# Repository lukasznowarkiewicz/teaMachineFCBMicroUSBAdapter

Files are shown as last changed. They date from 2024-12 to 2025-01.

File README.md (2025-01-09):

# teaMachineFCBMicroUSBAdapter

## Requirements
teaMachine used to use a COTS (Commercial Off-The-Shelf) micro USB cable. However, the connector is too large and does not fit when the device is fully assembled. Goal of the project was to design FPCB (flexible printed circuit board) which will connect touch panel to the raspberry pi zero (USB hub is only for debug pruposes)

Device

## Solution
To resolve this issue, a custom flexible printed circuit board (FPCB) was designed:
- Designed in **EasyEDA** (quick and COTS components to buy from LCSC).
- Utilized a micro USB plug from **LCSC**.
- Manufactured by **JLCPCB**.
- optimized the size to be smaller than 10x10cm (below those dimensions FPCB are for 2$, exceeding those dimensions can increase the prise easily even 10 times)

## Project Overview

### Prototyping

First prototypes has been made with 'PaperCAD' to test fit dimensions.

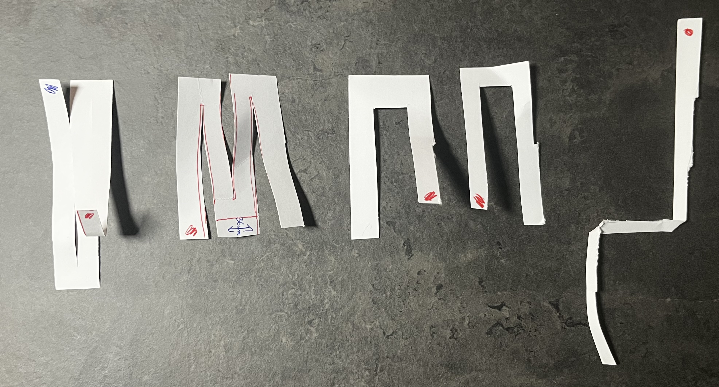
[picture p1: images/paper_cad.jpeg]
PaperCAD


### Stackup
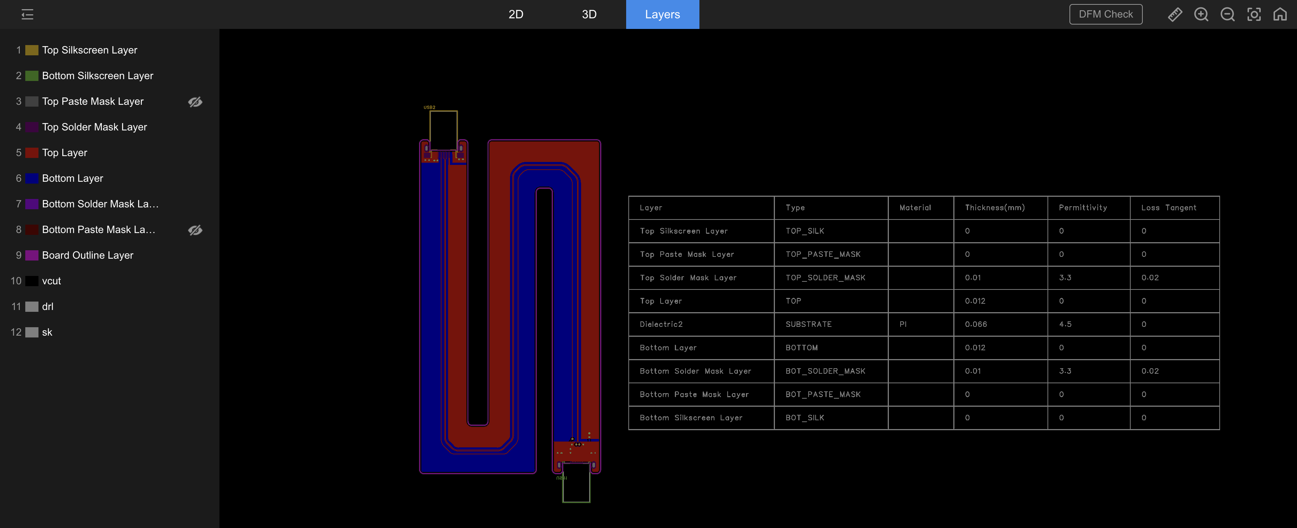
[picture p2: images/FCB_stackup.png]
FCB Stackup


### 3D Views
**Top View**  
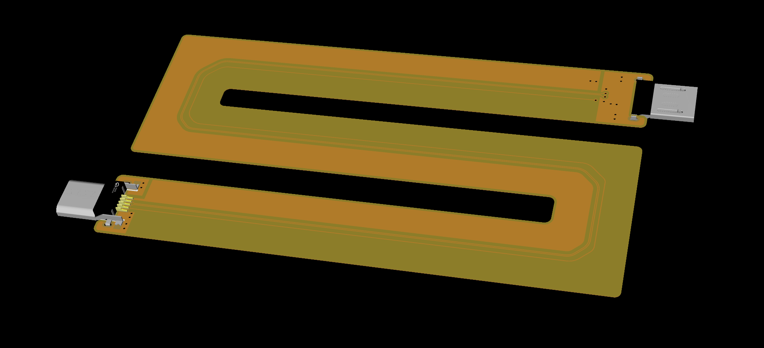
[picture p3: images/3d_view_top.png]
Top View


**Bottom View**  
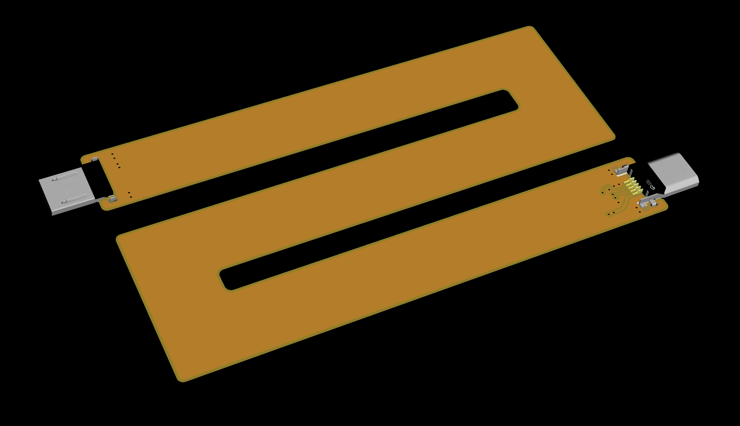
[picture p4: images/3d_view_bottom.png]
Bottom View


### Trace Design
**100 Ohm Differential Pair Routing**  
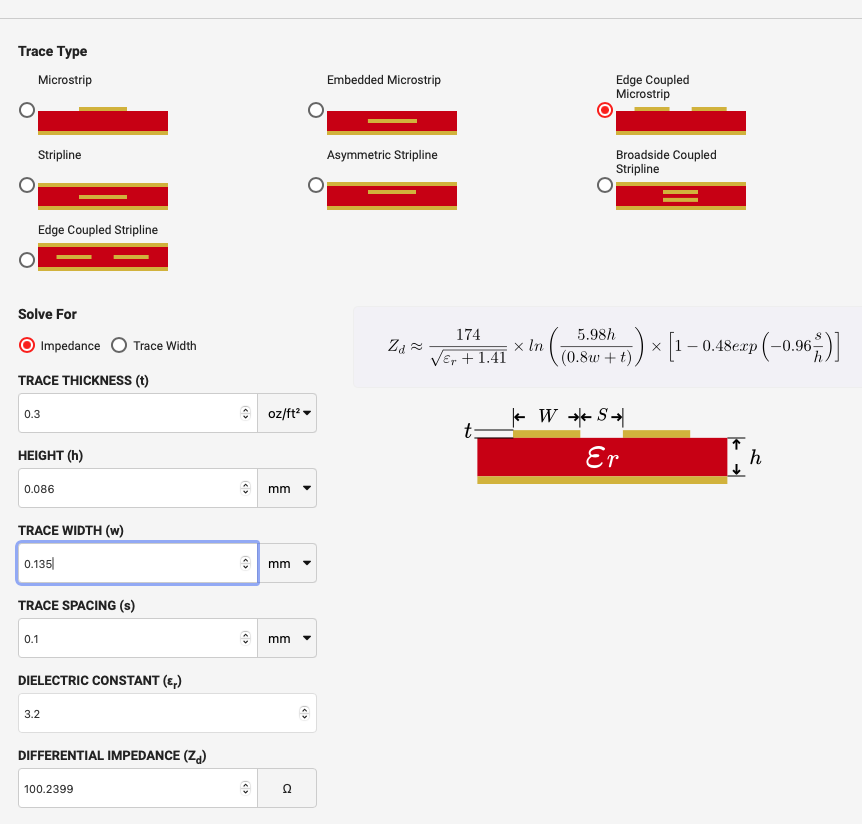
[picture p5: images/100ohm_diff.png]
100 Ohm Differential Pair


### Flex Preview
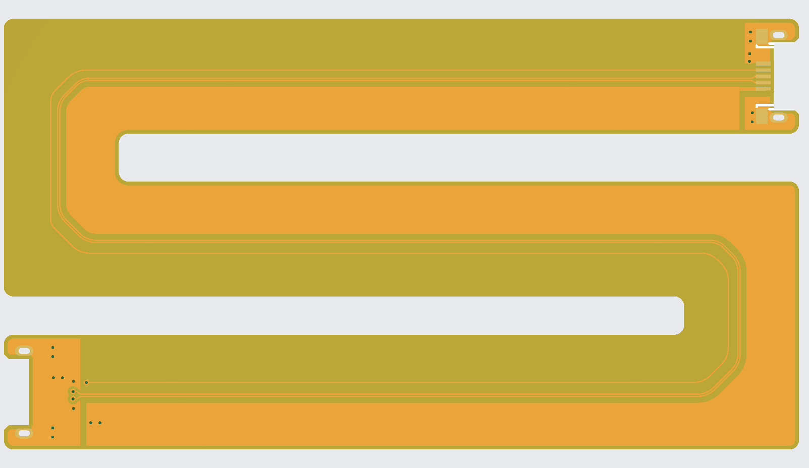
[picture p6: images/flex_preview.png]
Flex Preview


## Assembled flat cable

Assembled cable is working, dimensions are correct, only micro USB footprint is horrible to solder, so this should be corrected.

Assemled

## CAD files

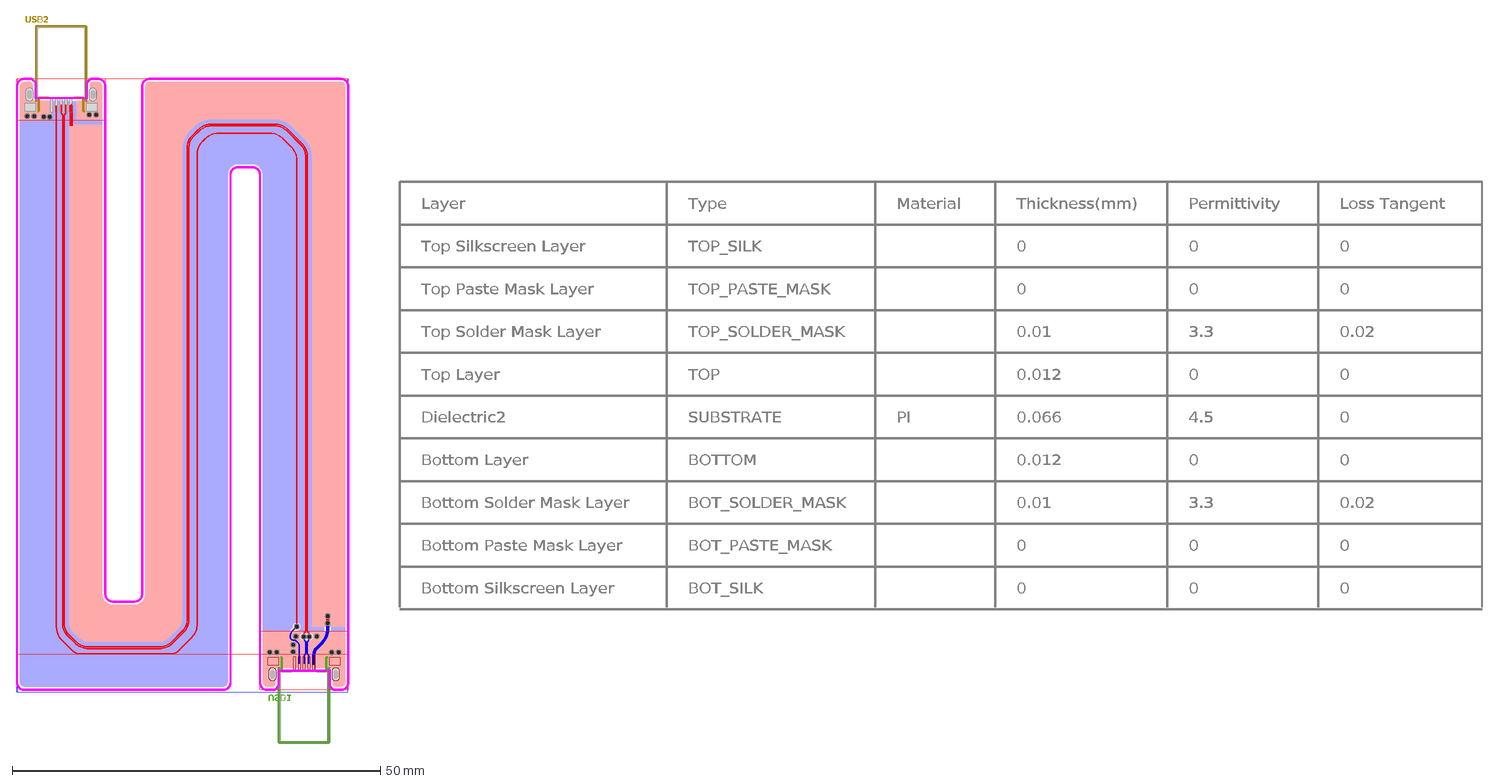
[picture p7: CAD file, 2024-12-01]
exports/DXF_PCB1_2024-12-01_AutoCAD2007.dxf
USB1
USB2
Layer
Type
Material
Thickness(mm)
Permittivity
Loss Tangent
Top Silkscreen Layer
TOP_SILK
0
Top Paste Mask Layer
TOP_PASTE_MASK
Top Solder Mask Layer
TOP_SOLDER_MASK
0.01
3.3
0.02
Top Layer
TOP
0.012
Dielectric2
SUBSTRATE
PI
0.066
4.5
Bottom Layer
BOTTOM
Bottom Solder Mask Layer
BOT_SOLDER_MASK
Bottom Paste Mask Layer
BOT_PASTE_MASK
Bottom Silkscreen Layer
BOT_SILK

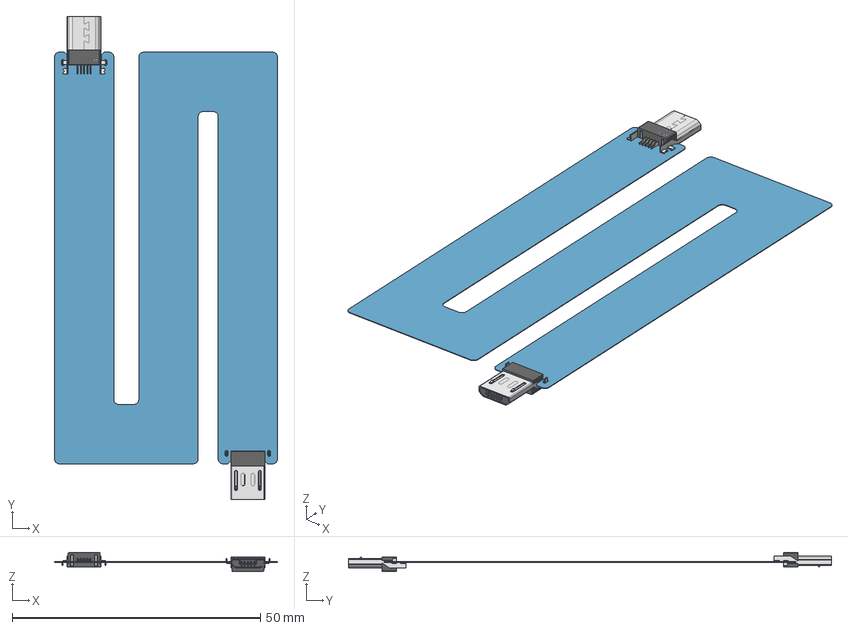
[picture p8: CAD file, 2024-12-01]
exports/3D_PCB1_2024-12-01.step
45.0 x 97.4 x 3.93 mm
TopTrack
BottomTrack
Board

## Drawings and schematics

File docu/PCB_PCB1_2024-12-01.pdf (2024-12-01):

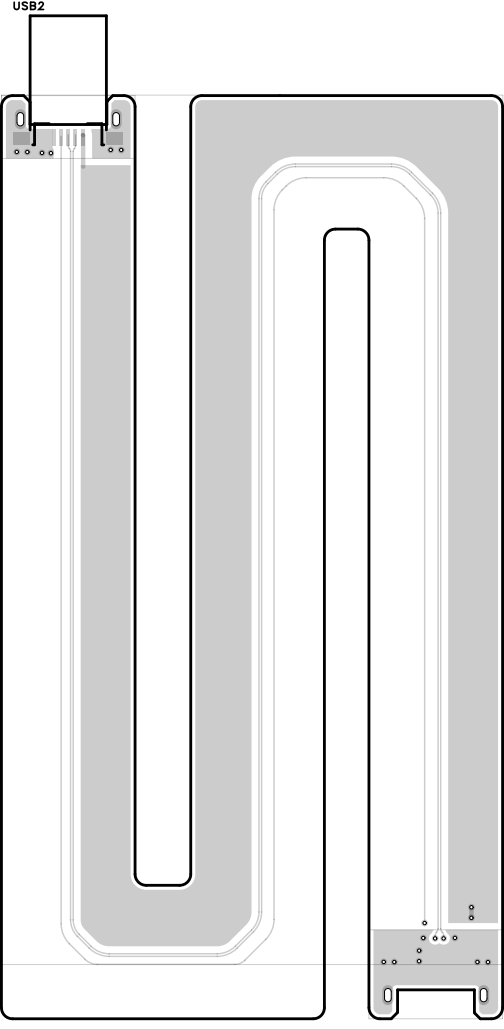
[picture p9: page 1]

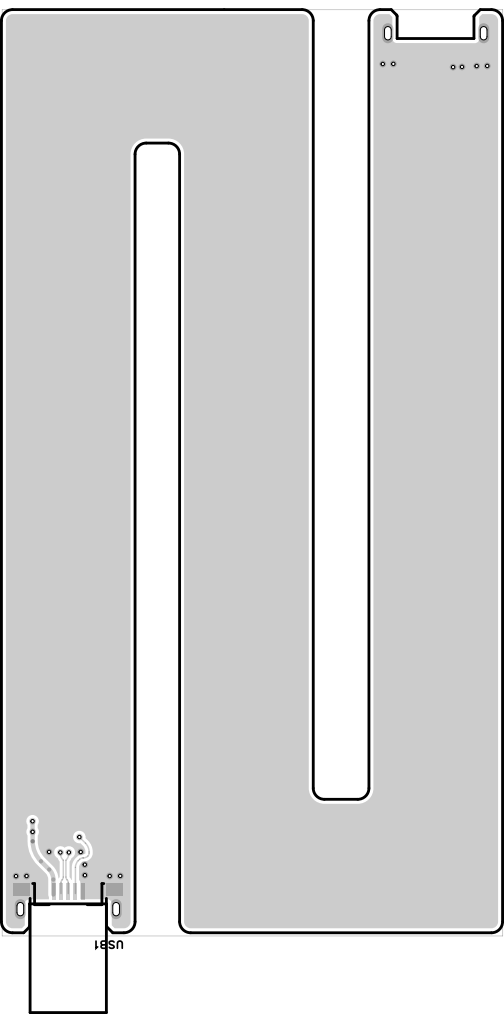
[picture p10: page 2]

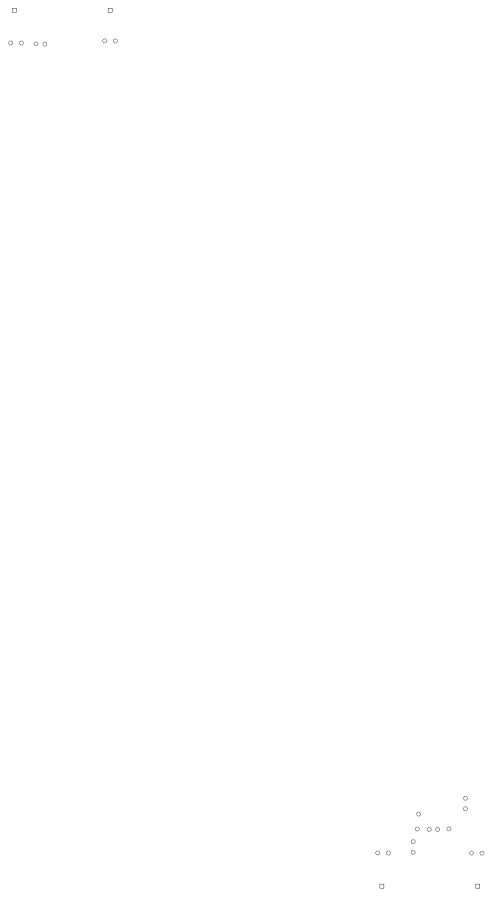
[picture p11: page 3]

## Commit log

2024-12-01 [#1] Add exported design to different formats
    [3D_PCB1_2024-12-01.step, DXF_PCB1_2024-12-01_AutoCAD2007.dxf]
2025-01-09 Update readme with assembled board
